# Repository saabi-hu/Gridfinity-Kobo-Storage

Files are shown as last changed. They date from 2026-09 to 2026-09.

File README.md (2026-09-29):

# Gridfinity Kobo Storage

A Gridfinity bin that keeps a **Kobo Clara Color** lying flat in a drawer.

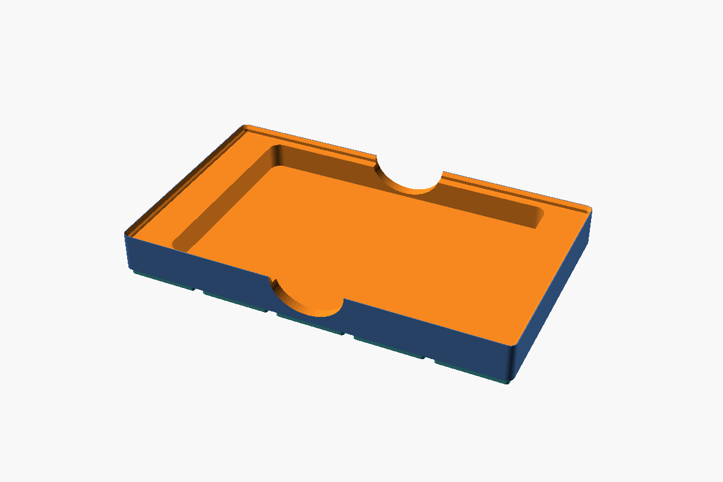
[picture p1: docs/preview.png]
Top view


## What's here

| File | What it is |
| --- | --- |
| `kobo_bin.scad` | Parametric OpenSCAD source (no external libraries needed) |
| `stl/kobo_bin_5x3x3.stl` | Ready-to-print STL with the default settings |

## Measurements used

| What | Value |
| --- | --- |
| Kobo Clara Color in its cover | 160 × 111 × 9.65 mm measured; sized for 161 × 112 mm to allow for ruler error |
| Pocket (1 mm clearance per side) | 163 × 114 mm, 6 mm corner radius |
| Bin footprint | 5 × 3 grid units, 209.5 × 125.5 mm |
| Bin height | 3 units (21 mm) + 4.4 mm stacking lip = 25.4 mm |
| Pocket depth | 14 mm from the floor to the rim (18.4 mm to the top of the lip) |
| Drawer inside height | 57 mm |

Height budget in the drawer: about 5 mm of baseplate + 25.4 mm of bin leaves roughly
26 mm of headroom. The tallest bin that still fits is 6 units (5 + 42 + 4.4 = 51.4 mm).

Two finger notches in the long walls let you pinch the reader out. They stop 2 mm
above the pocket floor.

## Customising

Open `kobo_bin.scad` in OpenSCAD and use the Customizer panel (Window > Customizer).
Useful knobs:

- `clearance`: loosen or tighten the fit after a test print.
- `device_thickness`: add the thickness of a sleep cover if you store it in one.
- `height_units`: up to 6 for a 57 mm drawer.
- `stacking_lip`: turn off for a flat rim.

Export with F6 (render) and then File > Export > STL, or from the command line:

```sh
openscad -o stl/kobo_bin_5x3x3.stl kobo_bin.scad
```

## Printing

- Print upright (feet down); no supports needed.
- 0.2 mm layers, 3 walls, 15 % infill is plenty.
- A felt or TPU pad on the pocket floor adds extra protection for the screen.

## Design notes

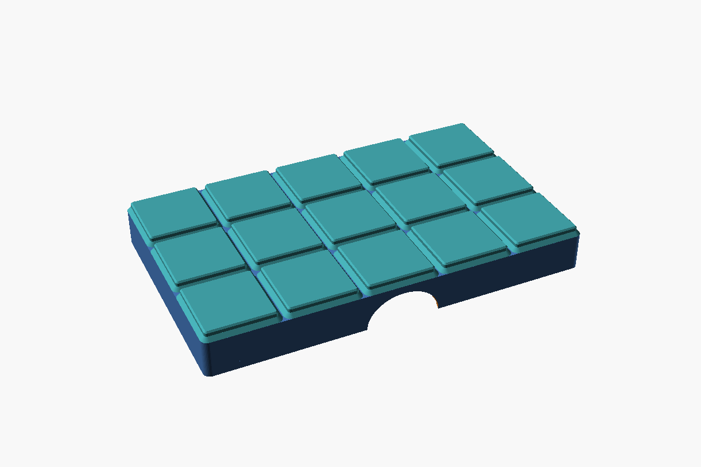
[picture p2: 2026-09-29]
docs/preview-bottom.png

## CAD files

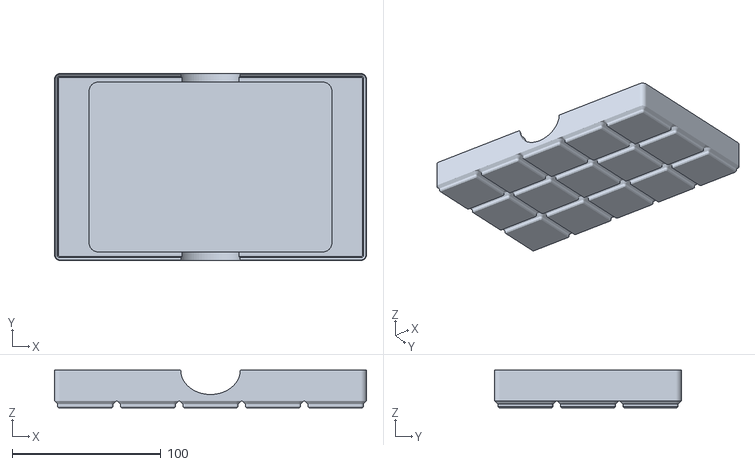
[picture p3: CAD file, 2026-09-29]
stl/kobo_bin_5x3x3.stl
209.5 x 125.5 x 25.4

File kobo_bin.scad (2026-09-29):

// Gridfinity bin that holds a Kobo Clara Color lying flat.
// Self-contained: needs no external OpenSCAD libraries.
// All dimensions in millimetres.

/* [Device] */
// Kobo Clara Color in its cover, long side (measured 160 on a ruler, +1 for reading error)
device_length = 161;
// Kobo Clara Color in its cover, short side (measured 111 on a ruler, +1 for reading error)
device_width = 112;
// Kobo Clara Color thickness with the cover closed (measured 9.65 with calipers)
device_thickness = 9.65;
// Gap between the device and the pocket wall, per side
clearance = 1.0;
// Corner radius of the pocket
pocket_corner_radius = 6;

/* [Bin] */
// Grid units along X (42 mm each)
grid_x = 5;
// Grid units along Y (42 mm each)
grid_y = 3;
// Height in 7 mm units, base included (max 6 for a 57 mm drawer with a 5 mm baseplate)
height_units = 3;
// Add the Gridfinity stacking lip on top
stacking_lip = true;
// Height of the solid floor, measured from the bottom of the bin
floor_top = 7;

/* [Finger notches] */
// Width of the notch at the rim
notch_width = 40;
// Material left between the notch bottom and the floor
notch_floor_margin = 2;

/* [Hidden] */
$fn = 64;
pitch = 42;
cell = 41.5;            // one cell of the bin, 0.5 mm smaller than the grid
outer_radius = 3.75;
base_height = 4.75;     // 0.8 chamfer + 1.8 vertical + 2.15 chamfer
lip_height = 4.4;       // 0.7 chamfer + 1.8 vertical + 1.9 chamfer
eps = 0.01;

bin_x = grid_x * pitch - 0.5;
bin_y = grid_y * pitch - 0.5;
bin_top = height_units * 7;

pocket_x = device_length + 2 * clearance;
pocket_y = device_width + 2 * clearance;

assert(pocket_x <= bin_x - 2 * 2.6, "Pocket too long for the grid, raise grid_x");
assert(pocket_y <= bin_y - 2 * 2.6, "Pocket too wide for the grid, raise grid_y");
assert(bin_top - floor_top >= device_thickness, "Pocket too shallow, raise height_units");

// Rounded rectangle slab, centred on XY, of thickness h starting at z.
module rrect(x, y, r, h, z = 0) {
    translate([0, 0, z])
        linear_extrude(h)
            offset(r = r) square([x - 2 * r, y - 2 * r], center = true);
}

// Rounded rectangle inset from the outer bin outline.
module inset_slab(inset, z, h = eps) {
    rrect(bin_x - 2 * inset, bin_y - 2 * inset, max(outer_radius - inset, 0.5), h, z);
}

// Standard Gridfinity foot for one grid cell.
module foot() {
    // (inset from cell edge, z)
    layers = [[2.95, 0], [2.15, 0.8], [2.15, 2.6], [0, base_height]];
    for (i = [0 : len(layers) - 2])
        hull() {
            for (l = [layers[i], layers[i + 1]])
                rrect(cell - 2 * l[0], cell - 2 * l[0],
                      max(outer_radius - l[0], 0.8), eps, l[1]);
        }
}

module feet() {
    for (ix = [0 : grid_x - 1], iy = [0 : grid_y - 1])
        translate([(ix - (grid_x - 1) / 2) * pitch,
                   (iy - (grid_y - 1) / 2) * pitch, 0])
            foot();
}

// Cavity that forms the inside of the stacking lip.
module lip_cavity() {
    layers = [[2.6, 0], [1.9, 0.7], [1.9, 2.5], [0.4, lip_height]];
    for (i = [0 : len(layers) - 2])
        hull() {
            for (l = [layers[i], layers[i + 1]])
                inset_slab(l[0], bin_top + l[1]);
        }
    inset_slab(0.4, bin_top + lip_height - eps, 1);
}

module pocket() {
    rrect(pocket_x, pocket_y, pocket_corner_radius,
          bin_top + lip_height - floor_top + 1, floor_top);
}

// Scooped notches in both long walls so the device can be pinched out.
module finger_notches() {
    top = bin_top + (stacking_lip ? lip_height : 0);
    depth = top - (floor_top + notch_floor_margin);
    translate([0, 0, top])
        rotate([90, 0, 0])
            scale([notch_width / 2 / depth, 1, 1])
                cylinder(r = depth, h = bin_y + 2, center = true);
}

module kobo_bin() {
    difference() {
        union() {
            feet();
            inset_slab(0, base_height - eps, bin_top - base_height + eps);
            if (stacking_lip)
                inset_slab(0, bin_top - eps, lip_height + eps);
        }
        if (stacking_lip) lip_cavity();
        pocket();
        finger_notches();
    }
}

kobo_bin();

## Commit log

2026-09-28 Add parametric Gridfinity bin for Kobo Clara Color
    4x3 grid, 3 height units, stacking lip, 146x114 mm pocket with finger
    notches. Includes rendered STL and preview images.
    Claude-Session: https://claude.ai/code/session_01HomkQKD6foMdfaqqheSrw4
    [kobo_bin.scad, kobo_bin_4x3x3.stl]
2026-09-28 Resize pocket for the Kobo in its cover (5x3 bin)
    The measured reader is 160 x 110 x 10 mm (+/- 5 mm), longer than the
    144 mm spec the 4x3 pocket was cut for. Size the pocket for the upper
    bound (165 x 115 mm, 14 mm deep) and grow the bin to 5 x 3 units.
    [kobo_bin.scad, kobo_bin_4x3x3.stl, kobo_bin_5x3x3.stl]
2026-09-28 Fit pocket to measured reader size (160 x 111 x 9.65 mm)
    Size for 161 x 112 mm to allow for ruler reading error; the pocket is
    163 x 114 mm. A 4x3 bin tops out at a 162.3 mm pocket, so keep 5x3.
    [kobo_bin.scad, kobo_bin_5x3x3.stl]
